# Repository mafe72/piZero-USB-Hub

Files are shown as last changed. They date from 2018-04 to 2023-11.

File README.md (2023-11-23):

### Description



A small 4 port USB hub for the Raspberry Pi Zero

### License

<div align="center"><br /></div>

This project is licensed under the Attribution-NonCommercial-ShareAlike CC BY-NC-SA 4.0 license. The full legal text of the license may be found in the LICENSE.txt file in this repository. For more information about this license, please visit 
the Creative Commons Foundation (https://creativecommons.org/licenses/by-nc-sa/4.0/).

Designed by Eladio Martinez

### Features

- 4 x USB 2.0 ports
- Micro USB upstream connector
- FE1.1s USB hub chip
- Solder pins for direct connection to the Raspberry Pi Zero
- Power jack connector for external 5v power source
- Optional jumpers to take power from upstream connector
- LED status indicators for each downstream port

Top Side
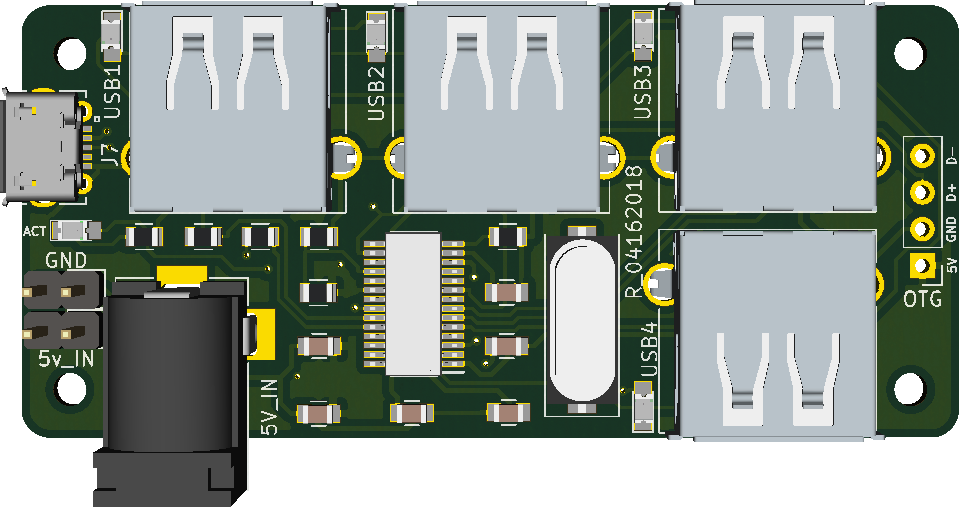
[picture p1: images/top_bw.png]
Top Side


Bottom Side
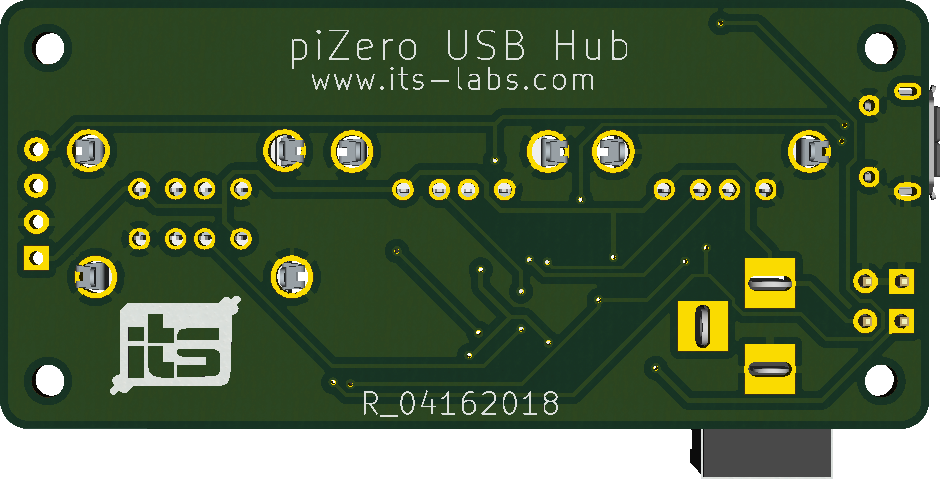
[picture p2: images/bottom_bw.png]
Bottom Side


### Modes of use

#### 1. Direct solder

You can solder 4 wires directly between the Zero and the hub using 4 pads exposed on both the hub and the Zero. This will connect the 5V, GND, USB D+ and USB D-.

You can then either power the board either using the USB power connector on the Zero, or using the power jack on the hub.

This is the neatest option, although does involve soldering.

#### 2. USB connection

Using a USB OTG cable, or a micro USB to micro USB you can connect the data USB port on the Zero to the upstream USB connector on the side of the hub. Adding the 2 power jumpers allows the hub to use power supplied to the Zero though the power USB connector.

Alternatively, remove the power jumpers and power the hub through the external power jack.

Although a USB cable is needed to connect the two in this mode, no soldering is required.

#### 3. Standalone hub

This board can be used as a regular USB hub, either using power from the upstream USB connector, or through the power jack and external power supply.

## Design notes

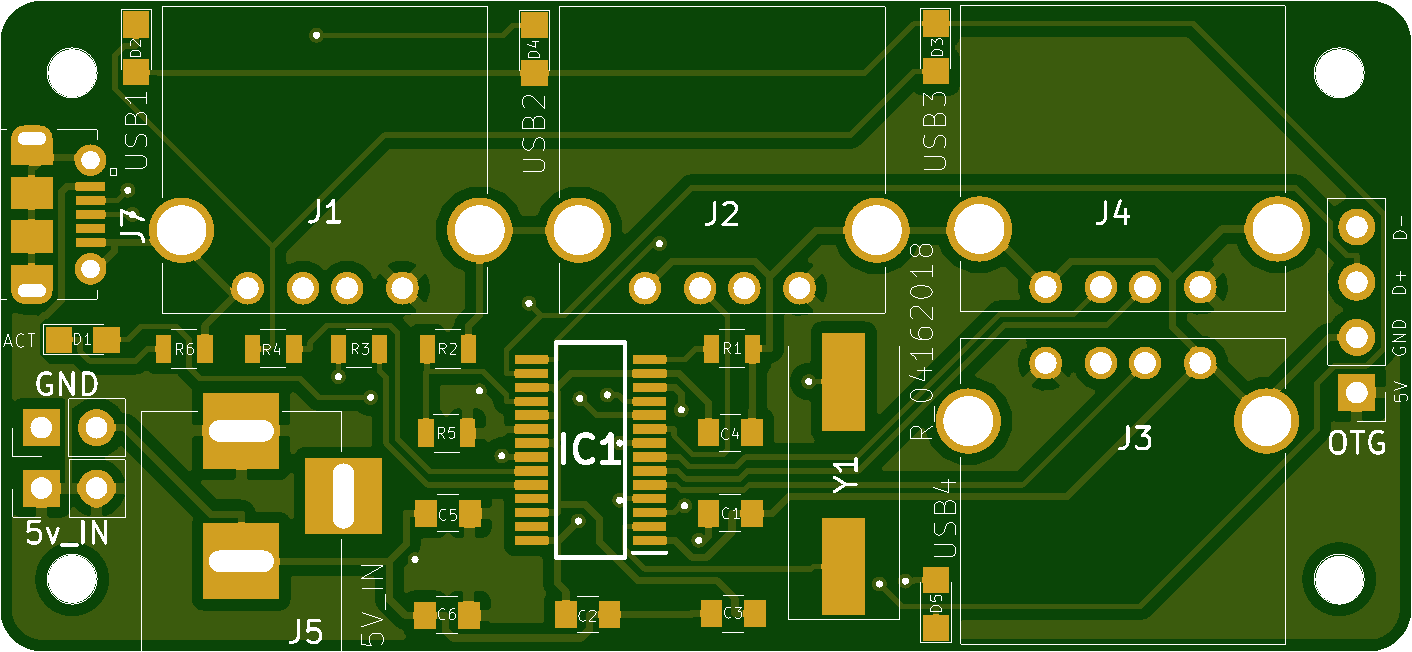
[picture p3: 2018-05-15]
images/top.png

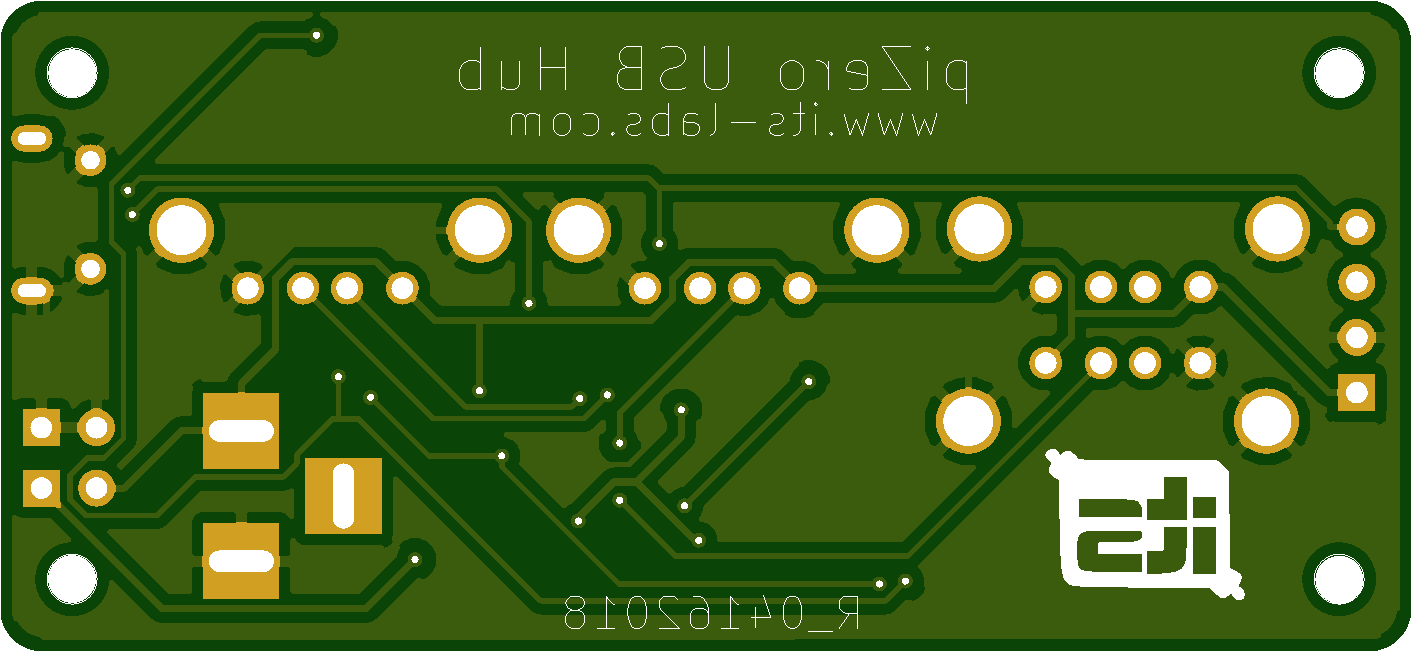
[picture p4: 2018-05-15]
images/bottom.png

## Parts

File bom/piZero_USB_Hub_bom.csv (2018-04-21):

Component | Description | References | Value | Footprint | Quantity Per PCB | Datasheet | MPN
1 | 0.1µF ±10% 100V Ceramic Capacitor X7R 0805 (2012 Metric) | C2 C4 C6 | 0.1uf | C_0805 | 3 | https://psearch.en.murata.com/capacitor/product/GCM21BR72A104KA37%23.pdf | GCM21BR72A104KA37K
2 | 10µF ±10% 25V Ceramic Capacitor X5R 0805 (2012 Metric) | C1 C3 C5 | 10uf | C_0805 | 3 | https://search.murata.co.jp/Ceramy/image/img/A01X/G101/ENG/GRM21BR61E106KA73-01.pdf | GRM21BR61E106KA73L
3 | Green 569nm LED Indication - Discrete 2.1V 0805 (2012 Metric) | D1 | ACT | LED_0805 | 1 | https://media.digikey.com/pdf/Data%20Sheets/Lite-On%20PDFs/LTST-C171GKT.pdf | LTST-C171GKT
4 | Green 569nm LED Indication - Discrete 2.1V 0805 (2012 Metric) | D2 | PORT1 | LED_0805 | 1 | https://media.digikey.com/pdf/Data%20Sheets/Lite-On%20PDFs/LTST-C171GKT.pdf | LTST-C171GKT
5 | Green 569nm LED Indication - Discrete 2.1V 0805 (2012 Metric) | D4 | PORT2 | LED_0805 | 1 | https://media.digikey.com/pdf/Data%20Sheets/Lite-On%20PDFs/LTST-C171GKT.pdf | LTST-C171GKT
6 | Green 569nm LED Indication - Discrete 2.1V 0805 (2012 Metric) | D3 | PORT3 | LED_0805 | 1 | https://media.digikey.com/pdf/Data%20Sheets/Lite-On%20PDFs/LTST-C171GKT.pdf | LTST-C171GKT
7 | Green 569nm LED Indication - Discrete 2.1V 0805 (2012 Metric) | D5 | PORT4 | LED_0805 | 1 | https://media.digikey.com/pdf/Data%20Sheets/Lite-On%20PDFs/LTST-C171GKT.pdf | LTST-C171GKT
8 | USB 2.0 HIGH SPEED 4-PORT HUB CONTROLLER | IC1 | FE1.1S | SOP64P600X175-28N | 1 | https://cdn-shop.adafruit.com/product-files/2991/FE1.1s Data Sheet (Rev. 1.0).pdf | FE1.1S
9 | USB - micro B USB 2.0 Receptacle Connector 5 Position Surface Mount, Right Angle; Through Hole | J7 | 105017-0001 | 105017-0001 | 1 | https://www.molex.com/pdm_docs/sd/1050170001_sd.pdf | 105017-0001
10 | Power Barrel Connector Jack 2.10mm ID (0.083"), 5.50mm OD (0.217") Through Hole, Right Angle | J5 | Barrel_Jack | BARREL_JACK | 1 | https://www.cui.com/product/resource/pj-002a.pdf | PJ-002A
11 | 2 Positions Header, Breakaway Connector Through Hole Tin | J9 | GND | Pin_Header_Straight_1x02_Pitch2.54mm | 1 | www.te.com/commerce/DocumentDelivery/DDEController?Action=srchrtrv&DocNm=103328&DocType=Customer+Drawing&DocLang=English | 4-103328-1
12 | 2 Positions Header, Breakaway Connector Through Hole Tin | J8 | PWR | Pin_Header_Straight_1x02_Pitch2.54mm | 1 | www.te.com/commerce/DocumentDelivery/DDEController?Action=srchrtrv&DocNm=103328&DocType=Customer+Drawing&DocLang=English | 4-103328-1
13 | USB - A USB 2.0 Receptacle Connector 4 Position Through Hole, Right Angle | J1 J2 J3 J4 | UE27AC54100 | USB_A | 4 | https://www.amphenolcanada.com/ProductSearch/drawings/AC/UE27ACX4X0X.pdf | UE27AC54100
14 | 4 Positions Header, Breakaway Connector 0.100" (2.54mm) Through Hole Tin | J6 | USB_OTG_AUX | Pin_Header_Straight_1x04_Pitch2.54mm | 1 | http://www.te.com/commerce/DocumentDelivery/DDEController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 | 5-146274-4
15 | 100 kOhms ±5% 0.4W, 2/5W Chip Resistor 0805 (2012 Metric) Automotive AEC-Q200, Pulse Withstanding Thick Film | R2 | 100k | R_0805 | 1 | https://www.rohm.com/datasheet/ESR01MZPF/esr-e | ESR10EZPJ104
16 | 2.7 Ohms ±5% 0.4W, 2/5W Chip Resistor 0805 (2012 Metric) Automotive AEC-Q200, Pulse Withstanding Thick Film | R1 | 2.7K | R_0805 | 1 | https://www.rohm.com/datasheet/ESR01MZPF/esr-e | ESR10EZPJ2R7
17 | 330 Ohms ±5% 0.125W, 1/8W Chip Resistor 0805 (2012 Metric) Automotive AEC-Q200 Thick Film | R3 R4 R6 | 330R | R_0805 | 3 | https://www.seielect.com/Catalog/SEI-RMCF_RMCP.pdf | RMCF0805JT330R
18 | 47 kOhms ±5% 0.4W, 2/5W Chip Resistor 0805 (2012 Metric) Automotive AEC-Q200, Pulse Withstanding Thick Film | R5 | 47K | R_0805 | 1 | https://www.rohm.com/datasheet/ESR01MZPF/esr-e | ESR10EZPJ473
19 | 12MHz ±30ppm Crystal 18pF 40 Ohms HC-49S | Y1 | HC-495 12Mhz | Crystal_SMD_HC49-SD | 1 | http://www.txccorp.com/download/products/quartz_crystals/2015TXC_9C_32.pdf | 9C-12.000MBBK-T

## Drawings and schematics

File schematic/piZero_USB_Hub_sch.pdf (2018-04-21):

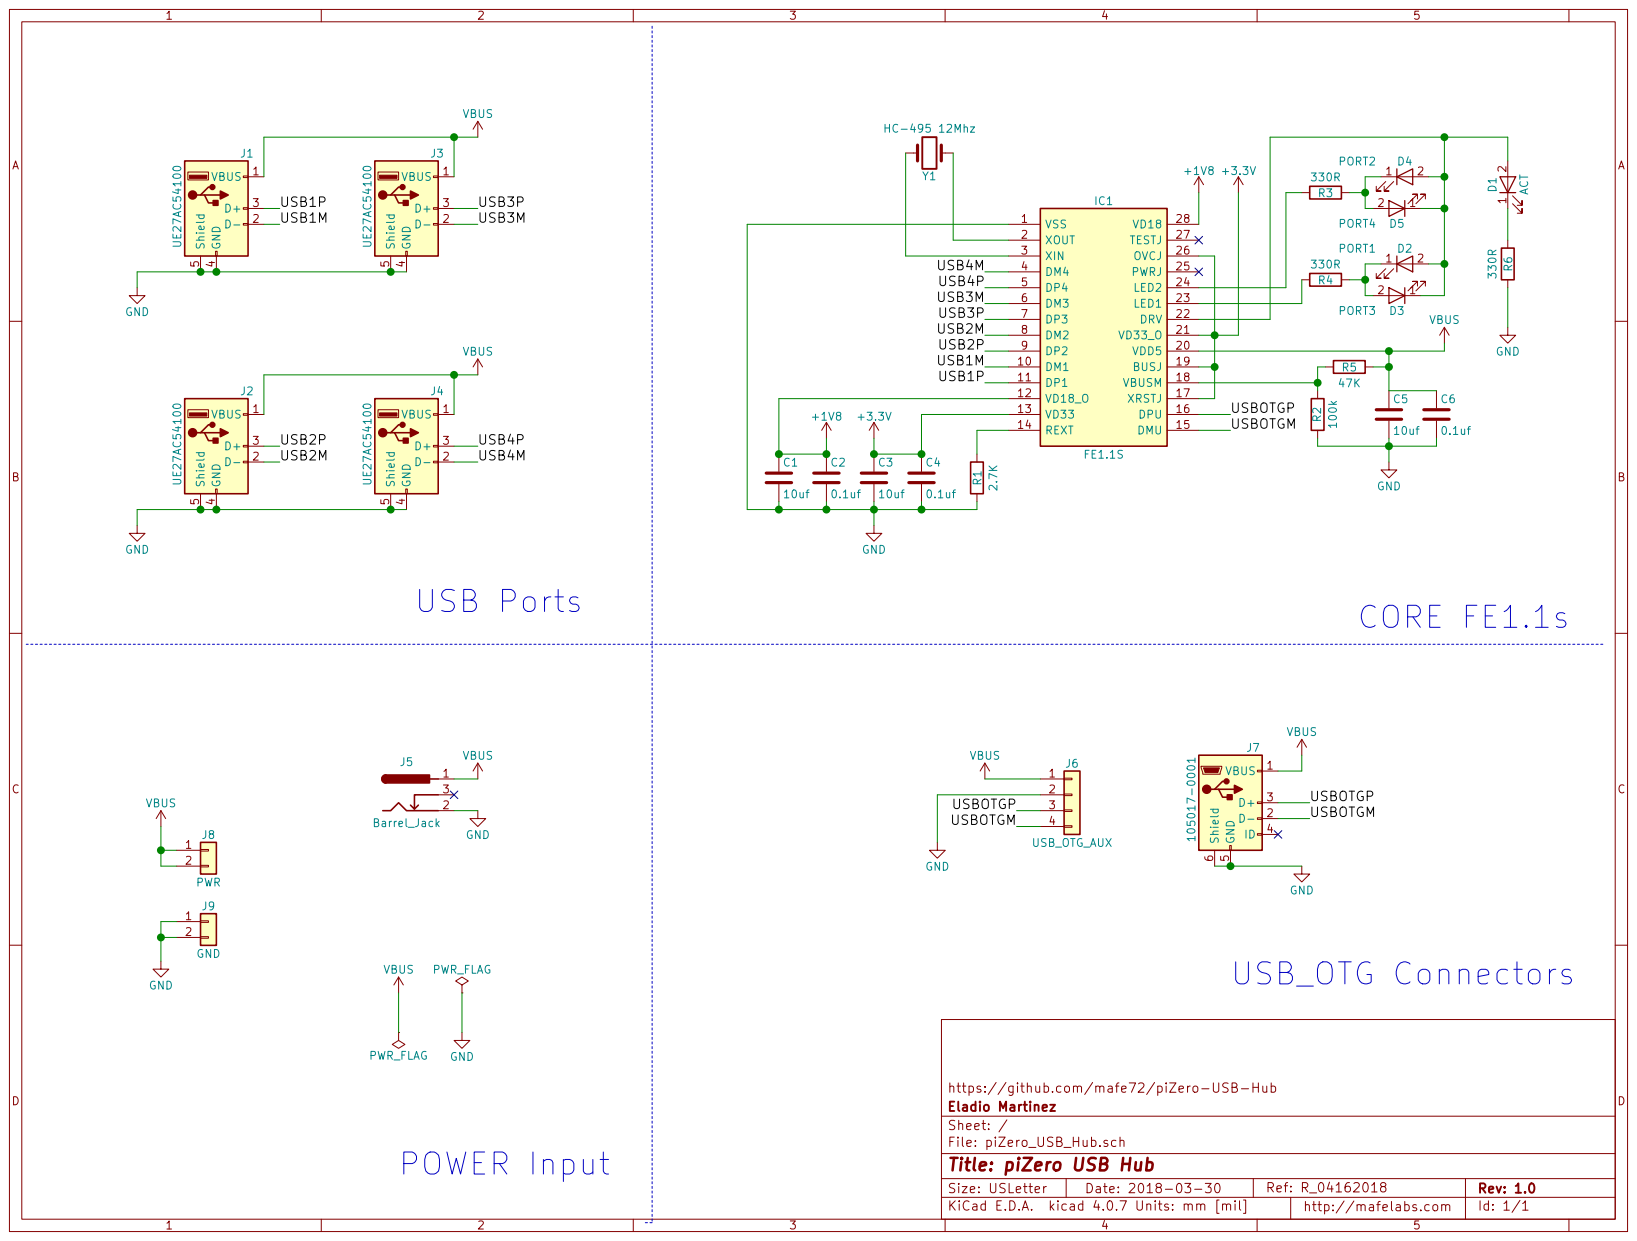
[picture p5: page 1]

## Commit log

2018-05-15 Align USB ports 3 & 4
    [piZero_USB_Hub-B.Cu.gbl, piZero_USB_Hub-B.Mask.gbs, piZero_USB_Hub-B.Paste.gbp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]
2018-09-14 Add Interactive bom
